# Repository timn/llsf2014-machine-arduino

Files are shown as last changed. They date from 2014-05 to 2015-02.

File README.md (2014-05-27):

Alternative Machine Controller for RoboCup Logistics League
===========================================================

This spare time project implements an alternative controller for the machines used in the [RoboCup Logistics League Sponsored by Festo](http://www.robocup-logistics.org) (LLSF). It is in no way supported or endorsed by the league, but was developed for internal testing and for the fun of it.

The controller is based on the Arduino Fio and communicates with the referee box (refbox) via ZigBee (using XBee modules). It requires a companion board which allows for controlling the signal lights at 24V and reading RFID tags on the pucks. It uses the Seeedstudio 125 KHz RFID reader and tags for this task and not the standard tags typically used in the LLSF. The design and schematics of this board is provided as a [Fritzing](http://fritzing.org) file and shown in the image below.

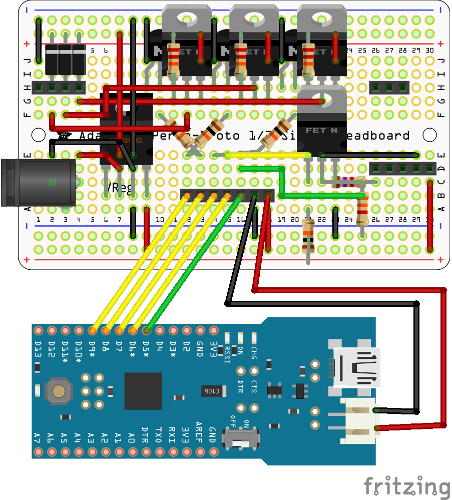
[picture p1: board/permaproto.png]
Fritzing view


Requirements
------------
- Arduino Fio:
  The Fio is used to run the control program. It has a socket for an XBee.
- XBee Modules:
  One Module for each machine and one for the refbox. For the refbox we have used the SparkFun XBee Explorer USB to host the board.
- Companion Board:
  The companion board you must built on your own. We provide schematics in the board directory with the partlist as partlist.txt.
- LLSF field equipment:
  These are in particular the light signals with metal frames (to which you need to mount the controller), the pucks, and RFID tags (125 KHz Tags matching the RFID reader).

The code has been developed using [Ino](http://inotool.org/). It allows for efficient builds and uploads from the command line and can be easily integrated with Emacs.

Running
-------
Compile and upload the code using

    ino build
    ino upload

For details on how to program the Arduino Fio cf. the [Arduino webpage](http://arduino.cc/en/Main/ArduinoBoardFioProgramming). Note that you must remove the XBee module for programming. Use Digi X-CTU to setup the XBee modules (on Linux use an older version, we have used 5.2.8.6). The module connected via the explorer USB to the refbox machine must be installed with the ZigBee coordinator API firmware (we have used version 21A7). Use the default settings. Set and remember the PAN ID (ID). Set the Node Identifier (NI) to "RefBox" (make sure there is no space at the beginning of the text field!). Next, upload the ZigBee Router API firmware to all of the field machine XBee modules. Set the PAN ID to the same value as the coordinator. Set the Node Identifier (NI) to the machine's name, e.g. M1 or D2.

Mount the XBee modules on the Arduinos and mount them to the machines with the companion board. After turning them on, they will automatically start looking for the RefBox. Once the LED on the boar turns off, a connection has been established and the machines can be used.

The Arduino pins 11 and 12 are set as a serial connection for debugging output. If you run into any problems connect with a TTL cable (3.3V!) at 9600 baud and check the output.

On the refbox, set the sps type to ArduinoXBee and the device to the serial port where the XBee Explorer USB is connected. The llsf-signal-ctrl, llsf-tool and the llsf-refbox main program will automatically pick up the new setting. Once started, you can set the lights using

    llsf-signal-ctrl -m M1 -r ON -y ON -g ON

Replace M1 by the desired machine and ON by OFF or BLINK respectively as desired.

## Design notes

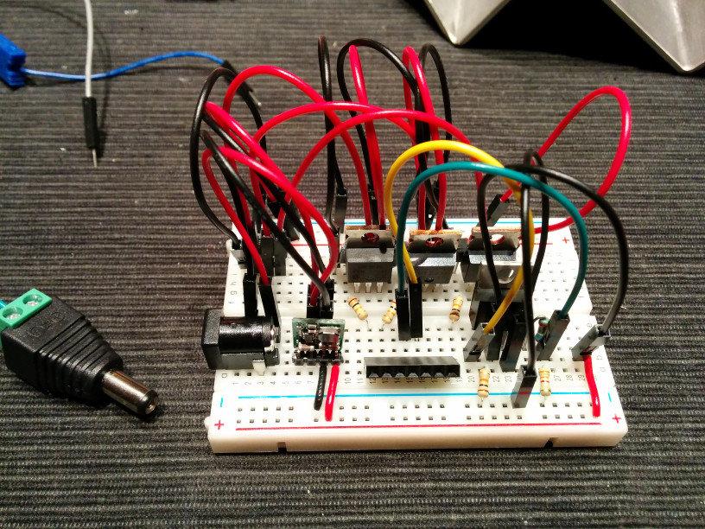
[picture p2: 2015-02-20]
board/breadboard_front.jpg

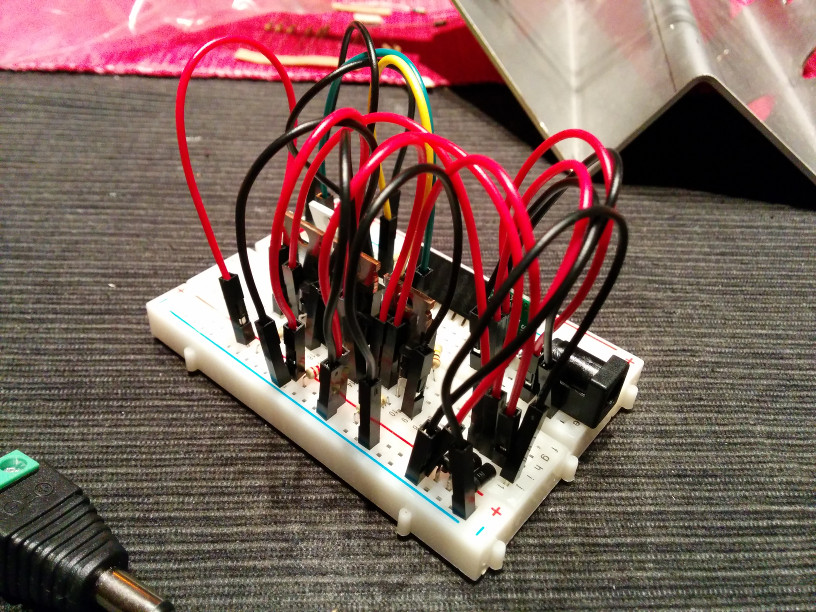
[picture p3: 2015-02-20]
board/breadboard_back.jpg

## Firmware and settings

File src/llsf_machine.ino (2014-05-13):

/***************************************************************************
 *  llsf_machine.ino - RoboCup LLSF Arduino-based machine
 *
 *  Created: Sat Apr 12 12:09:34 2014 (Nobis Pontstrasse, Aachen)
 *  Copyright  2014  Tim Niemueller [www.niemueller.de]
 ****************************************************************************/

/*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
 *  Read the full text in the LICENSE.GPL file in the doc directory.
 */

#include <TimerOne.h>
#include <XBee.h>
#include <SoftwareSerial.h>
#include <SeeedRFIDLib.h>

// *** PIN assignment for devices
#define PIN_GREEN     7
#define PIN_YELLOW    8
#define PIN_RED       9

#define PIN_RFID_RX   4
#define PIN_RFID_TX   5
#define PIN_RFID_POW  6

#define PIN_DEBUG_RX 11
#define PIN_DEBUG_TX 12

#define PIN_ERR_LED  13


#define RFID_TIMEOUT 1500

/** Light signal state. */
typedef enum {
  SIGNAL_OFF   = 0,	//< Light is turned off
  SIGNAL_ON    = 1,	//< Light is turned on
  SIGNAL_BLINK = 2	//< Light is blinking.
} SignalState;

// ERR 1 - 3 are reserved for XBee library
#define ERR_REFBOX_UNKNOWN    5
#define ERR_UNKNOWN_PACKET    6
#define ERR_SHORT_PACKET      7
#define ERR_INVALID_RESPONSE  8
#define ERR_INVALID_RFID_TAG  9

static const char * ERROR_CODES[] = {
  "No error",
  "Checksum failure",
  "Invalid AT command",
  "Invalid AT parameter",
  "No response to AT command",
  "RefBox unknown",
  "Unknown packet type",
  "Packet too short",
  "Invalid response received",
  "Invalid tag read"
};

// *** network message types
#define MSG_TYPE_SIGNAL_INSTRUCT  1
#define MSG_TYPE_SET_RED          2
#define MSG_TYPE_SET_YELLOW       3
#define MSG_TYPE_SET_GREEN        4
#define MSG_TYPE_RFID_DATA        5
#define MSG_TYPE_RFID_REMOVED     6
#define MSG_TYPE_RFID_WRITE       7

#pragma pack(push,1)
typedef struct {
  uint8_t  msg_type;
  uint32_t tag_id;
} RFIDMessage;

typedef struct {
  uint8_t signal_state_red;
  uint8_t signal_state_yellow;
  uint8_t signal_state_green;
} SignalInstructMessage;
#pragma pack(pop)

// *** refbox address data
XBeeAddress64 refbox_hw_addr_(0,0);
uint16_t      refbox_net_addr_ = 0;
uint8_t       refbox_dn_frame_id_ = 0;

RFIDMessage   rfid_report_msg_;
uint8_t       rfid_report_frame_id_ = 0;

// *** Internal state info
bool blink_state_ = false;
SignalState state_red_    = SIGNAL_ON;
SignalState state_yellow_ = SIGNAL_ON;
SignalState state_green_  = SIGNAL_ON;

uint8_t     frame_id_     = 0;

bool          rfid_visible_ = false;
unsigned long rfid_last_seen_ = 0;


// *** Interaction devices
SoftwareSerial debug(PIN_DEBUG_RX, PIN_DEBUG_TX);
XBee           xbee;
SeeedRFIDLib   rfid(PIN_RFID_RX, PIN_RFID_TX);


// from Ethernet library, repeat to avoid pulling in the whole thing
#define htons(x) ( ((x)<<8) | (((x)>>8)&0xFF) )
#define ntohs(x) htons(x)

#define htonl(x) ( ((x)<<24 & 0xFF000000UL) | \
                   ((x)<< 8 & 0x00FF0000UL) | \
                   ((x)>> 8 & 0x0000FF00UL) | \
                   ((x)>>24 & 0x000000FFUL) )
#define ntohl(x) htonl(x)

// *** Forward declarations
void blink_timer();
void update_lights();
void report_error(uint8_t err_num);
uint8_t next_frame_id();


// *** Setup program
void setup()
{
  pinMode(PIN_GREEN,    OUTPUT);
  pinMode(PIN_YELLOW,   OUTPUT);
  pinMode(PIN_RED,      OUTPUT);

  pinMode(PIN_ERR_LED,  OUTPUT);
  pinMode(PIN_RFID_POW, OUTPUT);

  digitalWrite(PIN_GREEN,    HIGH);
  digitalWrite(PIN_YELLOW,   HIGH);
  digitalWrite(PIN_RED,      HIGH);
  digitalWrite(PIN_ERR_LED,  HIGH);
  digitalWrite(PIN_RFID_POW, HIGH);

  Timer1.initialize(250000);
  Timer1.attachInterrupt(blink_timer);

  debug.begin(9600);
  debug.println("STARTED");

  // Restart once to make the RFID's internal SoftwareSerial become
  // the active listener -- there can only be one
  // we don't care for reading on the debug SoftwareSerial anyway
  rfid.restart();

  Serial.begin(9600);
  xbee.begin(Serial);
}


// *** Program loop
void loop()
{
  // if refbox address is unknown, send request. Re-send if the failed
  if (refbox_hw_addr_.getMsb() == 0 && refbox_dn_frame_id_ == 0) {
    report_error(ERR_REFBOX_UNKNOWN);
    digitalWrite(PIN_ERR_LED, HIGH);
    refbox_dn_frame_id_ = next_frame_id();
    AtCommandRequest req((uint8_t*)"DN", (uint8_t*)"RefBox", 6);
    req.setFrameId(refbox_dn_frame_id_);
    xbee.send(req);
  }

  // Read incoming XBee messages
  xbee.readPacket();
  if (xbee.getResponse().isError()) {
    debug.print("Response Error: ");
    debug.println(xbee.getResponse().getErrorCode());
    report_error(xbee.getResponse().getErrorCode());
  } else if (xbee.getResponse().isAvailable()) {
    if (xbee.getResponse().getApiId() == ZB_RX_RESPONSE) {
      ZBRxResponse rx;
      xbee.getResponse().getZBRxResponse(rx);
      //process message
      uint16_t data_length = rx.getDataLength();
      if (data_length >= 1) {
	digitalWrite(PIN_ERR_LED, LOW);

	uint8_t *data = rx.getFrameData() + rx.getDataOffset();

	debug.print("Received: ");
	for (unsigned int i = 0; i < data_length; ++i) {
	  debug.print(data[i], HEX);
	}
	debug.println("");

	uint8_t msg_type = data[0];
	switch (msg_type) {
	case MSG_TYPE_SIGNAL_INSTRUCT:
	  if (data_length == sizeof(SignalInstructMessage) + 1) {
	    SignalInstructMessage *msg = (SignalInstructMessage *)&data[1];
	    state_red_    = (SignalState)msg->signal_state_red;
	    state_yellow_ = (SignalState)msg->signal_state_yellow;
	    state_green_  = (SignalState)msg->signal_state_green;

	    debug.print("Received SignalInstructMessage: R ");
	    debug.print(state_red_);
	    debug.print("   Y "); debug.print(state_yellow_);
	    debug.print("   G "); debug.println(state_green_);

	    update_lights();
	  } else {
	    debug.println("Invalid SignalInstructMessage data length");
	  }
	  break;

	case MSG_TYPE_SET_RED:
	  if (data_length == 2) {
	    state_red_    = (SignalState)data[1];
	    update_lights();
	  } else {
	    debug.println("Invalid SET_RED data length");
	  }
	  break;

	case MSG_TYPE_SET_YELLOW:
	  if (data_length == 2) {
	    state_yellow_    = (SignalState)data[1];
	    update_lights();
	  } else {
	    debug.println("Invalid SET_RED data length");
	  }
	  break;

	case MSG_TYPE_SET_GREEN:
	  if (data_length == 2) {
	    state_green_    = (SignalState)data[1];
	    update_lights();
	  } else {
	    debug.println("Invalid SET_RED data length");
	  }
	  break;

	default: // unknown packet type
	  debug.print("Received unknown packet");
	  report_error(ERR_UNKNOWN_PACKET);
	  break;
	}
      } else {
	debug.print("Packet too short");
	report_error(ERR_SHORT_PACKET);
      }
    } else if (xbee.getResponse().getApiId() == MODEM_STATUS_RESPONSE) {
      ModemStatusResponse msr;
      xbee.getResponse().getModemStatusResponse(msr);
      debug.print("Modem status: ");
      debug.println(msr.getStatus());
    } else if (xbee.getResponse().getApiId() == AT_COMMAND_RESPONSE) {
      AtCommandResponse atr;
      xbee.getResponse().getAtCommandResponse(atr);
      uint8_t *command = atr.getCommand();
      if (command[0] == 'D' && command[1] == 'N' && atr.getFrameId() == refbox_dn_frame_id_) {
	refbox_dn_frame_id_ = 0;

	if (atr.getStatus() == SUCCESS) {
	  uint8_t *payload = atr.getValue();
	  refbox_net_addr_ = ((uint64_t)payload[0] << 8)  +  payload[1];

	  uint32_t msb = 
	    ((uint32_t)payload[2] << 24) + ((uint32_t)payload[3] << 16) +
	    ((uint32_t)payload[4] << 8)  +  payload[5];
	  uint32_t lsb = 
	    ((uint32_t)payload[6] << 24) + ((uint32_t)payload[7] << 16) +
	    ((uint32_t)payload[8] << 8)  +  payload[9];

	  refbox_hw_addr_.setMsb(msb);
	  refbox_hw_addr_.setLsb(lsb);

	  debug.print("RefBox: Net ");
	  for (int i = 0; i < 2; ++i)  debug.print(payload[i], HEX);
	  debug.print("  HW ");
	  for (int i = 2; i < 10; ++i)  debug.print(payload[i], HEX);
	  debug.print(" (");
	  debug.print(refbox_hw_addr_.getMsb(), HEX);
	  debug.print(" ");
	  debug.print(refbox_hw_addr_.getLsb(), HEX);
	  debug.print(")");
	  debug.println("");

	  digitalWrite(PIN_ERR_LED, LOW);
	}
      }
    } else if (xbee.getResponse().getApiId() == ZB_TX_STATUS_RESPONSE) {
      ZBTxStatusResponse txr;
      xbee.getResponse().getZBTxStatusResponse(txr);
      uint8_t frame_id = txr.getFrameId();
      if (rfid_report_frame_id_ == frame_id) {
	rfid_report_frame_id_ = 0;
      }
    } else {
      debug.println("Invalid response");
      report_error(ERR_INVALID_RESPONSE);
    }
  } // else no new data to process and no error

  // Read and send RFID tag if received
  // do not send if refbox address unknown or sending currently in progress
  if (refbox_hw_addr_.getMsb() != 0 && rfid_report_frame_id_ == 0) {
    if(rfid.isIdAvailable()) {
      // we have an RFID tag, read it and send it if valid
      RFIDTag tag = rfid.readId();
      if (tag.valid) {
	if (! rfid_visible_) {
	  debug.print("RFID tag detected: ");
	  debug.println(tag.id, HEX);
	  rfid_visible_ = true;
	}
	rfid_last_seen_ = millis();

	// restart RFID so we get continuous readings
	digitalWrite(PIN_RFID_POW, LOW);
	delay(5);
	digitalWrite(PIN_RFID_POW, HIGH);
	rfid.restart();

	rfid_report_msg_.tag_id   = tag.id;

	rfid_report_frame_id_ = next_frame_id();
	rfid_report_msg_.msg_type = MSG_TYPE_RFID_DATA;
      
	ZBTxRequest txr(refbox_hw_addr_, (uint8_t*)&rfid_report_msg_, sizeof(RFIDMessage));
	txr.setAddress16(refbox_net_addr_);
	txr.setFrameId(rfid_report_frame_id_);
	xbee.send(txr);
      } else {
	report_error(ERR_INVALID_RFID_TAG);
      }
    } else {
      unsigned long now = millis();
      if (now < rfid_last_seen_) {
	debug.println("RFID last seen overflow");
	// overflow, restart
	rfid_last_seen_ = now;
      }
      if (rfid_visible_ && ((now - rfid_last_seen_) > RFID_TIMEOUT)) {
	debug.println("RFID tag lost");
	rfid_visible_ = false;

	uint8_t msg_type = MSG_TYPE_RFID_REMOVED;

	rfid_report_frame_id_ = next_frame_id();
	ZBTxRequest txr(refbox_hw_addr_, &msg_type, 1);
	txr.setAddress16(refbox_net_addr_);
	txr.setFrameId(rfid_report_frame_id_);
	xbee.send(txr);
      }
    }
  }

  delay(20);
}


/** Timer to blink lights if set to do so. */
void blink_timer()
{
  blink_state_ = ! blink_state_;

  if (state_red_ == SIGNAL_BLINK)
    digitalWrite(PIN_RED, blink_state_ ? HIGH : LOW);

  if (state_green_ == SIGNAL_BLINK)
    digitalWrite(PIN_GREEN, blink_state_ ? HIGH : LOW);

  if (state_yellow_ == SIGNAL_BLINK)
    digitalWrite(PIN_YELLOW, blink_state_ ? HIGH : LOW);
}


void update_lights()
{
  if (state_red_ == SIGNAL_OFF) {
    debug.println("Red OFF");
    digitalWrite(PIN_RED, LOW);
  } else if (state_red_ == SIGNAL_ON) {
    debug.println("Red ON");
    digitalWrite(PIN_RED, HIGH);
  }

  if (state_yellow_ == SIGNAL_OFF) {
    debug.println("Yellow OFF");
    digitalWrite(PIN_YELLOW, LOW);
  } else if (state_yellow_ == SIGNAL_ON) {
    debug.println("Yellow ON");
    digitalWrite(PIN_YELLOW, HIGH);
  }

  if (state_green_ == SIGNAL_OFF) {
    debug.println("Green OFF");
    digitalWrite(PIN_GREEN, LOW);
  } else if (state_green_ == SIGNAL_ON) {
    debug.println("Green ON");
    digitalWrite(PIN_GREEN, HIGH);
  }
}

void report_error(uint8_t err_num)
{
  debug.print("Error: "); debug.print(err_num);
  debug.print(" - "); debug.println(ERROR_CODES[err_num]);

  digitalWrite(PIN_ERR_LED, LOW);
  delay(300);

  for (int i = 0; i < err_num; ++i) {
    digitalWrite(PIN_ERR_LED, HIGH);
    delay(200);
    digitalWrite(PIN_ERR_LED, LOW);
    delay(200);
  }
}

uint8_t next_frame_id()
{
  // zero means ignore frame id
  if (++frame_id_ == 0)  frame_id_ = 1;
  return frame_id_;
}

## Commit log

2014-04-12 Arduino-based LLSF machine program
    This programm can run on an Arduino Fio to control a LLSF machine. This
    initial base program uses an interrupt timer to blink lights (if set to
    do so).
2014-04-17 XBee communication, signal control, refbox addressing info
    Added the XBee library to communicate with the refbox. The current code
    can handle an incoming SignalControlMessage to set the light signal
    state (and execute it). It also queries for the refbox addressing
    information if not already set for sending out info later.
2014-05-13 lib: modified SeeedRFIDLib to communicate with RFID
    The modifications are mainly to allow for smaller builds which support
    only one specific communication mode. We set this to UART and leave out
    Wiegand support.
2014-05-13 Process LED setting, communication improvements
2014-05-13 RFID sensor reading and sending of messages
    Read the RFID sensor if the refbox has been found on the network and
    send out messages indicating when it is available or was lost.
2014-05-15 Fritzing board design
    The accompanying board that drives the signal lights and RFID device. It
    is based on the soldered prototype and includes breadboard view and
    schematic.
    [board.fzz]
2015-02-20 board: add photos of breadboard prototype

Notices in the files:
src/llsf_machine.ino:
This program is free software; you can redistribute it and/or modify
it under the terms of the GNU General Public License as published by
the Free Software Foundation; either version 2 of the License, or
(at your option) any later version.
